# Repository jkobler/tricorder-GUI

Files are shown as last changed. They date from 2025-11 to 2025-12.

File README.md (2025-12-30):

# tricorder-GUI
**I'm building a fully (esque) functional TOS-era [Tricorder](http://www.racprops.com/issue5/classictricorder/index.php) using Arduino C++ and assorted compatibles.** 

## Task List
- [X] Blinky Lights™
- [X] Get TFT working
- [X] Make Menu System
- [X] Make Stardate Calculator
- [ ] Connect Working RTC
- [X] Button 1 and Button 2 do things like back and forward
- [X] Get I2C bus functioning
- [ ] Connect hood MCU to body MCU
- [X] Get Navigation Encoder Connected and Working
	- [X] ..Solder Encoder to Breakout Board
- [ ] Move components from breadboard to functional connects
- [ ] Solder switchs and Blink Lights™ to perf board then to hood MCU GPIO pins, or GPIO extender
- [ ] Solder TFT to hood MCU SPI pins
- [ ] Route power connections
- [ ] Get battery system working with low charge warning and charge status
- [ ] Print 3D parts.
- [ ] Standby mode
- [ ] Auto shutoff
- [ ] screen brightness
- [ ] audio
	- [ ] microphone and recording
	- [ ] speaker and audio playback
	- [ ] volume, gain, timbre(?)
- [ ] video
	- [ ] camera(s) and recording
	- [ ] video playback
- [ ] infrared camera and monitoring
- [ ] all the sensors
- [ ] Write the rest of this list
- [ ] Initiate scope creep.

## Current Schematics
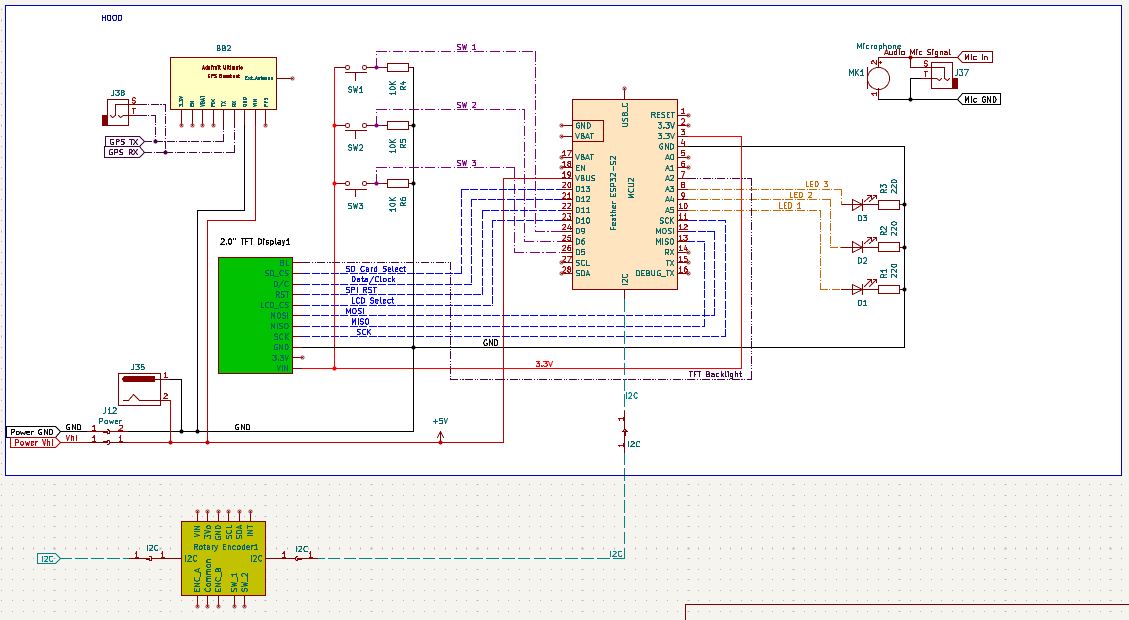
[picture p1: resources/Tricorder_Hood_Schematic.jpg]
Wiring Diagram


## LOGS

### 2025-11-16

It all started when I started 3D printing a [Tricorder](https://cults3d.com/en/3d-model/various/tos-tricorder-with-empty-compartment) model and then thought to myself, "Hey, I should put a little screen along with an MCU and then make it do tricorder stuff." It kind of went from there. 

So far, I have a working first go at a GUI, which I had to take liberties with as there were very few times we ever saw the little screen on the hero models. I tried to keep a look and feel that I thought might be privelent in the mid-23rd century, and not go full LCARS with it. Personally, I don't like LCARS but that's me. I went with something a bit more minimalistic and easy to read on the small 320x240 sceen. Long, indented losenges.

I have stubs for some of the features. I did get a basic image veiwer working as well as a text reader. I also have blinky lights™. You can't have a tricorder without the blinky lights™, now can you? The answer is 'no' as if that question needs an answer. ALWAYS BLINKY LIGHTS™!

As of right now I plan on sticking with ESP32 processors as they seem to have the speed and memory to handle everything without issue. I currently have an [Adafruit Metro ESP32-S2](https://www.adafruit.com/product/2488) as the processor now, which is running the screen and the blinky lights™. I plan on using a smaller [Adafruit ESP32-S2 Feather](https://www.adafruit.com/product/5000) for the [Adafruit 2.2" ILI9341 based TFT](https://www.adafruit.com/product/1480), the blinky lights™ of course, and the buttons. All of these should fit up in the hood along with the screen, and require only power and I2C connections routed from the body. There will also probably be a microphone in the hood but I would prefer it be connected to the body processor which will most likely be the Adafruit Metro ESP32-S2 I already have in play. 

#### Punchdown List

| Auxilliary Device | Pin On Aux | MCU | Pin On MCU | Wire Color |
| :--- | :--- | :--- | :--- | :--- |
| 2.2" TFT | FPC Conn | EYESPI | FPC Conn | |
| EYESPI | Vin | Metro ESP32-S2 | 3.3 | |
| EYESPI | Gnd | Metro ESP32-S2 | GND | |
| EYESPI | SCK | Metro ESP32-S2 | SCK | blue |
| EYESPI | MOSI | Metro ESP32-S2 | MOSI | orange |
| EYESPI | MISO | Metro ESP32-S2 | | |
| EYESPI | DC | Metro ESP32-S2 | D9 | yellow |
| EYESPI | RST | Metro ESP32-S2 | RST | brown |
| EYESPI | TCS | Metro ESP32-S2 | D10 | green |
| EYESPI | SDSC | Metro ESP32-S2 | D12 | gray |
| SWITCH1 | 1 | Metro ESP32-S2 | D7 | purple |
| SWITCH1 | 2 | Metro ESP32-S2 | GND | black |
| SWITCH2 | 1 | Metro ESP32-S2 | D8 | yellow |
| SWITCH2 | 2 | Metro ESP32-S2 | GND | black |
| SWITCH3 | 1 | Metro ESP32-S2 | D6 | orange |
| SWITCH3 | 2 | Metro ESP32-S2 | GND | black |
| SWITCH4 | 1 | Metro ESP32-S2 | D5 | blue |
| SWITCH5 | 2 | Metro ESP32-S2 | GND | black |
| BlinkyLight1 | Anode | Metro ESP32-S2 | D13 | red | 
| BlinkyLight1 | Cathode | Metro ESP32-S2 | GND | 10kΩ |  
| BlinkyLight2 | Anode | Metro ESP32-S2 | D14 | white | 
| BlinkyLight2 | Cathode | Metro ESP32-S2 | GND | 10kΩ |  
| BlinkyLight3 | Anode | Metro ESP32-S2 | D15 | brown | 
| BlinkyLight3 | Cathode | Metro ESP32-S2 | GND | 10kΩ |  
| | | | |  

##### Display Punchdown List

| Auxilliary Device | Pin On Aux | MCU | Pin On MCU | Wire Color |
| :--- | :--- | :--- | :--- | :--- |
| 2.2" TFT | GND | Metro ESP32-S2 | GND | black |
| 2.2" TFT | VIN | Metro ESP32-S2 | 3.3 | brown |
| 2.2" TFT | D/C | Metro ESP32-S2 | D9 | red |
| 2.2" TFT | RST | Metro ESP32-S2 | RST | orange |
| 2.2" TFT | SDCS | Metro ESP32-S2 | D12 | yellow |
| 2.2" TFT | CS | Metro ESP32-S2 | D10 | green |
| 2.2" TFT | MOSI | Metro ESP32-S2 | MOSI | blue |
| 2.2" TFT | MISO | Metro ESP32-S2 | MISO | purple |
| 2.2" TFT | SCK | Metro ESP32-S2 | SCK | gray |
| 2.2" TFT | BL | Metro ESP32-S2 | XXXXXXXXXX | white |

##### Switch Array Punchdown List

| Auxilliary Device | Pin On Aux | MCU | Pin On MCU | Wire Color |
| :--- | :--- | :--- | :--- | :--- |
| SWITCH1 | | Metro ESP32-S2 | D7 | purple |
| SWITCH2 | | Metro ESP32-S2 | D8 | green |
| GND | | Metro ESP32-S2 | GND | blue |

##### Blinky Lights™ Array Punchdown List

| Auxilliary Device | Pin On Aux | MCU | Pin On MCU | Wire Color |
| :--- | :--- | :--- | :--- | :--- |
| LED1 | | Metro ESP32-S2 | D13 | purple |
| LED2 | | Metro ESP32-S2 | D14 | green |
| LED3 | | Metro ESP32-S2 | D15 | blue |
| GND | | Metro ESP32-S2 | GND | black |

### 2025-12-17

Had to take break to print parts, order parts, and work on other projects, but I was able to hook up the blinky lights™ on a [Adafruit GPIO Extender](https://www.adafruit.com/product/4886) and the encoder with an [Adafruit Rotary Encoder Breakout](https://www.adafruit.com/product/4991) to the [Adafruit ESP32-S2 Feather](https://www.adafruit.com/product/5000). That works so much nicer. The lights can fade in and out which is classy af.

I almost forgot to mention I bought I new 3D-printer which is what brought me back into this full berries. My Creality Ender 3 S1 Plus has unfortunately ended up with a warped hot bed, I imagine because it is rather wide and long, but also perhaps because I didn't let it cool slower. Just theories, but I can't find a replacement hotbed for it, and since we have the laser cutter attachment which isn't so sensitive to tram and level issues, it will be for laser cutting from here on out. I replaced it with an Anycubic Kobra S1 combo kit with the ACE filament box which allows me to do multicolor. So far it has been wonderful. I mean, I was printing right out of the box which I couldn't do with the Creality.

While the Ender 3 was I struggle sometimes, I don't regret getting it. I learned a lot, and when it worked, it worked well. For the price point, it worked well. I will still be able to use it as mentioned, for laser cutting. I would still be using it if Creality hadn't abandon making replacement parts for it a year after I bought it, but such are things with bleeding edge technology I guess.

Nonetheless, I can now print my tricorder parts after making changes necessary for fitting the parts.

Ok, back to the Tricorder.

I also picked up a couple of [Adafruit 2.0" 320x240 TFT Displays](https://www.adafruit.com/product/4311) from Digikey which will provide better fitment. The goal is to get one working with the ESP32-S2 Feather along with everything else so the buttons and encoder can interact with the menu system. I am going to ditch the EYESPI board. It's great for debugging and prototyping but room is a factor and the ribbon cable doesn't fit so I will have to direct solder, maybe with a different connector between for easy replacement. Adafruit has more of the 2.0" TFTs back in stock so I'll probably order more from there. It's nice to have spares, not to mention like all projects this is merely the prototype. Actually, the next 5 will mostly be prototypes too if I'm being honest here.

I printed a handy test stand for my hood parts (STL is included in this repo) that will assist me in prototype and

I'm going to have to change to the buttons inputting to and the LEDs fed from the MCU directly. There just isn't going to be room in the hood for the GPIO Extender, not to mention it really didn't spare me any hassle as I still had to solder. I intend on using pulse width modulation to get the same fade in and out effect though.

For switches I found these awesome badboys on DigiKey, [Pushbutton Switch SPST-NO](https://www.digikey.com/en/products/detail/e-switch/800AWSP9M2QE/502069). Not tactile but they fit well. I re-make the train wheel buttons to fit over these. I'll probably pull them down to ground with 10KΩ resisters.

At this point I need to decide how I want to connect the blinky lights™, switches, and TFT to the MCU, and find connectors that will work for this setup.  

#### Punchdown List (expected)

| Auxilliary Device | Pin On Aux | MCU | Pin On MCU | Pull Up/Down  | Wire Color |
| :--- | :--- | :--- | :--- | :--- | :--- |
| 2.0" TFT | Vin | ESP32-S2 Feather | 3.3 | | |
| 2.0" TFT | 3Vo | | | | |
| 2.0" TFT | Gnd | ESP32-S2 Feather | GND | | |
| 2.0" TFT | SCK | ESP32-S2 Feather | SCK | | |
| 2.0" TFT | MISO | ESP32-S2 Feather | MI | | |
| 2.0" TFT | MOSI | ESP32-S2 Feather | MO | | |
| 2.0" TFT | CS | ESP32-S2 Feather | D13 (GPIO14) | | |
| 2.0" TFT | RST | ESP32-S2 Feather | D12 (GPIO14) | | |
| 2.0" TFT | D/C | ESP32-S2 Feather | D11 (GPIO14) | | |
| 2.0" TFT | SDSC | ESP32-S2 Feather | D10 (GPIO14) | | |
| 2.0" TFT | BL | ESP32-S2 Feather | | | |
| SWITCH1 | 1 | ESP32-S2 Feather | D9 (GPIO9) | 10kΩ to GND | |
| SWITCH1 | 2 | ESP32-S2 Feather | 3.3V | | |
| SWITCH2 | 1 | ESP32-S2 Feather | D6 (GPIO6) | 10kΩ to GND | |
| SWITCH2 | 2 | ESP32-S2 Feather | 3.3V | | |
| SWITCH3 | 1 | ESP32-S2 Feather | D5 (GPIO5) | 10kΩ to GND | |
| SWITCH3 | 2 | ESP32-S2 Feather | 3.3V | | |
| BlinkyLight1 | Cathode | ESP32-S2 Feather | A5 (GPIO8) | | | 
| BlinkyLight1 | Anode | ESP32-S2 Feather | 3.3V | 220Ω to 3.3V  | |  
| BlinkyLight2 | Cathode | ESP32-S2 Feather | A4 (GPIO14)  | | | 
| BlinkyLight2 | Anode | ESP32-S2 Feather | 3.3V | 220Ω to 3.3V  | |  
| BlinkyLight3 | Cathode | ESP32-S2 Feather | A3 (GPIO15)  | | | 
| BlinkyLight3 | Anode | ESP32-S2 Feather | 3.3V | 220Ω to 3.3V  | |  

##### I2C Bus

| Auxilliary Device | Address | MCU | Constant Name | 
| :--- | :--- | :--- | :--- |
| Encoder Breakout  | 0x36 | ESP32-S2 Feather | SEESAW_ADDR |

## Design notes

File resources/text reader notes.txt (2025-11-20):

For a number of years work has been proceeding in order to bring perfection to the crudely conceived idea of a machine that would not only supply inverse reactive current for use in unilateral phase detractors, but would also be capable of automatically synchronizing cardinal grammeters.  Such a machine is the Turbo-Encabulator. Basically, the only new principle involved is that instead of power being generated by the relative motion of conductors and fluxes, it is produced by the modial interaction of magneto-reluctance and capacitive directance.

text = For a number of years work has been proceeding in order to bring perfection to the crudely conceived idea of a machine that would not only supply inverse reactive current for use in unilateral phase detractors, but would also be capable of automatically synchronizing cardinal grammeters.

  int pageNumber = 0;
  int lastChar = 0;
  int maxCharsPerScreen = 0;
  int textLength = 288;
  byte linesPerScreen =11;
  //int avgCharWidth=0;
  byte charsPerLine = 38;
  bool stillReading = true;
  int i=0,lastSpaceInLine=0,lineCount=0, estLinesTotal = (textLength/(charsPerLine))+2;
  char lineBuffer[charsPerLine+1];
  char formattedText[estLinesTotal][charsPerLine+1];

LOOP over characters (ch) in text , ch < textLength; Bascially ch is 0 to 287
	
	LOOP over characters to fill a line. i < charsPerLine && ch < textLength;  i is 0 to 38
		
		if ch is a space, newline, or punctuation, record i (by the lineBuffer being built) as lastSpaceInLine

		add this character to lineBuffer in idx i
	                                                    0         1         2         3    3      
	                                                    0123456789012345678901234567890123456789
	                                                    For a number of years work has been proc
														abcdefghijklmnopqrstuvwxyzABCDEFGHIJKLMNO
														abcdefghijklmnopqrstuvwxyzABCDEFGHIJKL MNO
    scenarios                                                                     lastSpaceInLine                ch
      1. We've transversed the whole line (i = 38), we are still ch<textLength, 
         and there is a white space character before that but past 60% (23)       The last space encountered;    back to last white space.
      2. We've hit the end of the text (ch >= textLength)                         i-1;                           no change
      3. We've transversed the whole line (i = 38), we are still ch<textLength,   i-1;                           no change
         there is either no whitespace before 60%, but there is whitespace the 
         next character up.
      4. We've transversed the whole line (i = 38), we are still ch<textLength,   i-1;                           no change
         there is either no whitespace before 60%.
														
scenario 1
			ch = 38 (index)
			i=38 (index)
			lastSpaceInLine = 35 (index)
			charsPerLine = 38 (total)
			ch correction = 38-35+1 = 2

	END LOOP ch < charsPerLine && ch < textLength
	
	if the next character in the text (text(ch+1)) is a space, newline, or punctuation, record i (by the lineBuffer being built) as lastSpaceInLine and ch+1 < textLength then lastSpaceInLine = i
	
	copy 

For a number of years work has been proce           41
eding in order to bring perfection to the cru       45
dely conceived idea 
of a machine that would not only supply inv         43
erse reactive current for use in unilateral ph      46
ase detractors, 
but would also be capable of automatically          43
synchronizing cardinal grammeters.  Such a          44
machine is the 
Turbo-Encabulator. Basically, the only new          43
principle involved is that instead of power b       45
eing generated by the relative motion of conductors and fluxes, it is produced by the modial interaction of magneto-reluctance and capacitive directance.

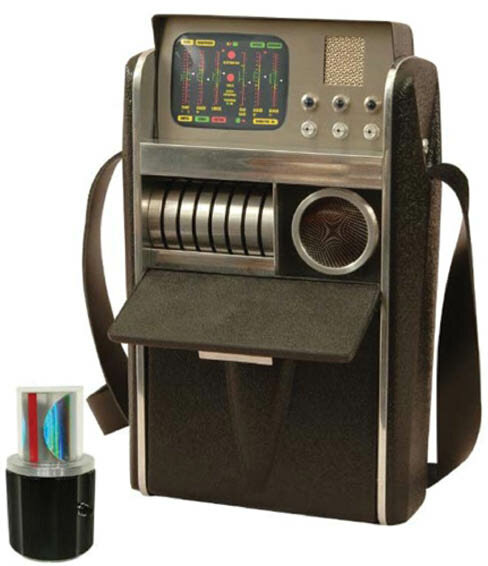
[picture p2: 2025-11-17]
resources/images/reference photos/hero/The-original-Tricorder-model-and-probe-used-on-the-Star-Trek-television-series-designed.png

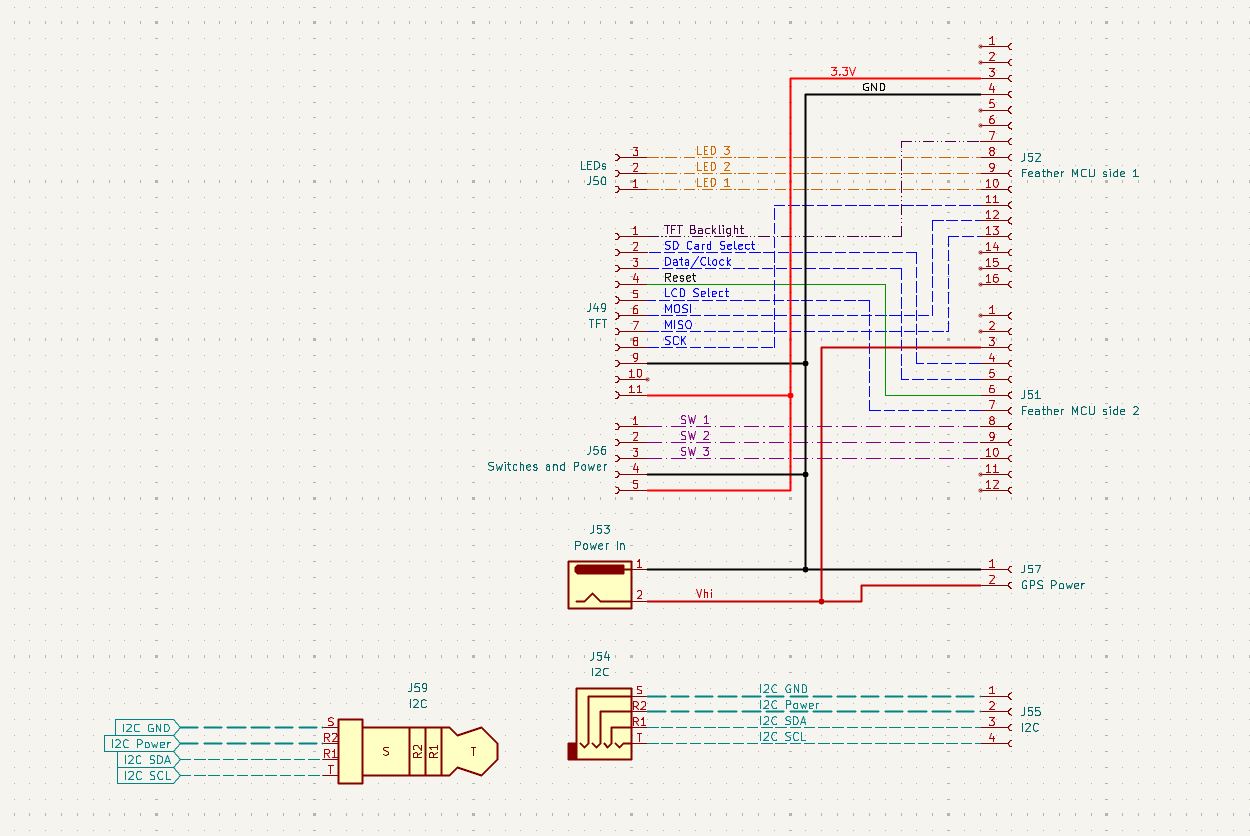
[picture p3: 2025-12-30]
resources/Tricorder_Hood_Wire_Harness_Schematic.jpg

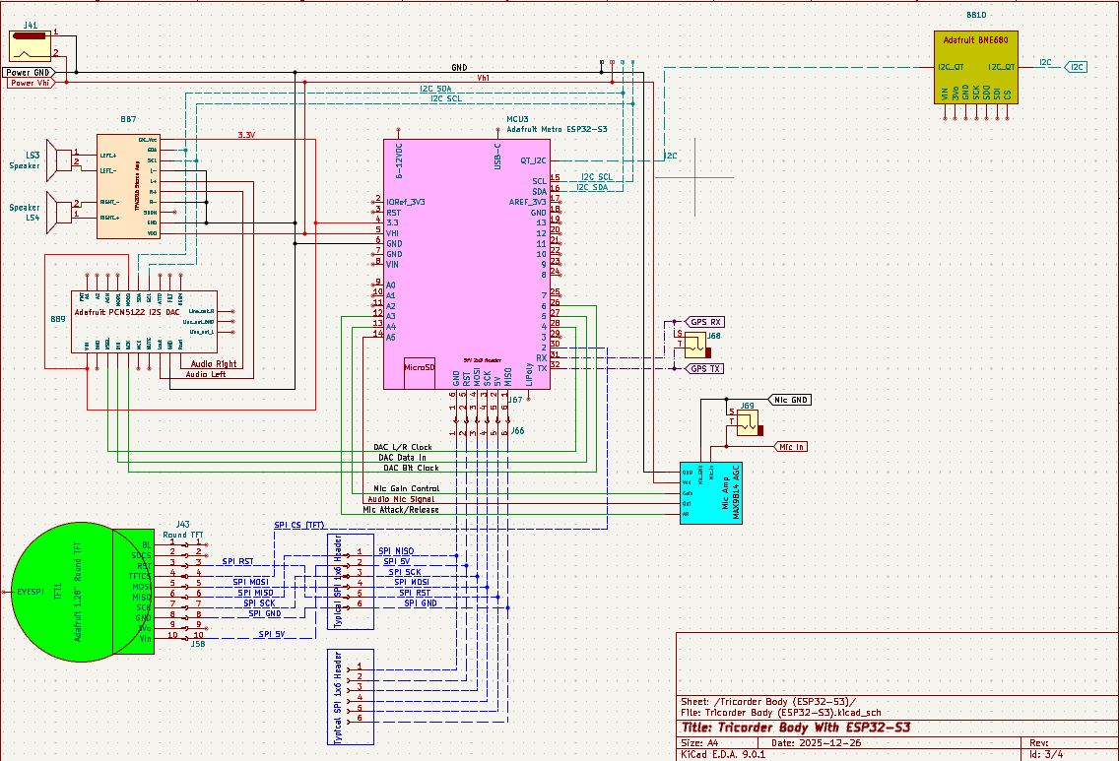
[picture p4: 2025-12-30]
resources/Tricorder_Body_Schematic.jpg

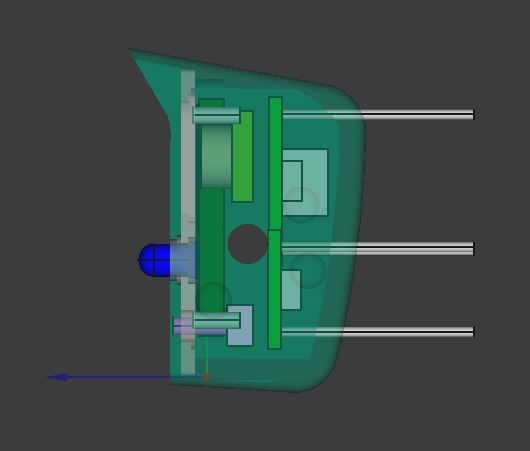
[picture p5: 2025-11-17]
resources/images/reference photos/layout/Tricorder hood-Right.JPG

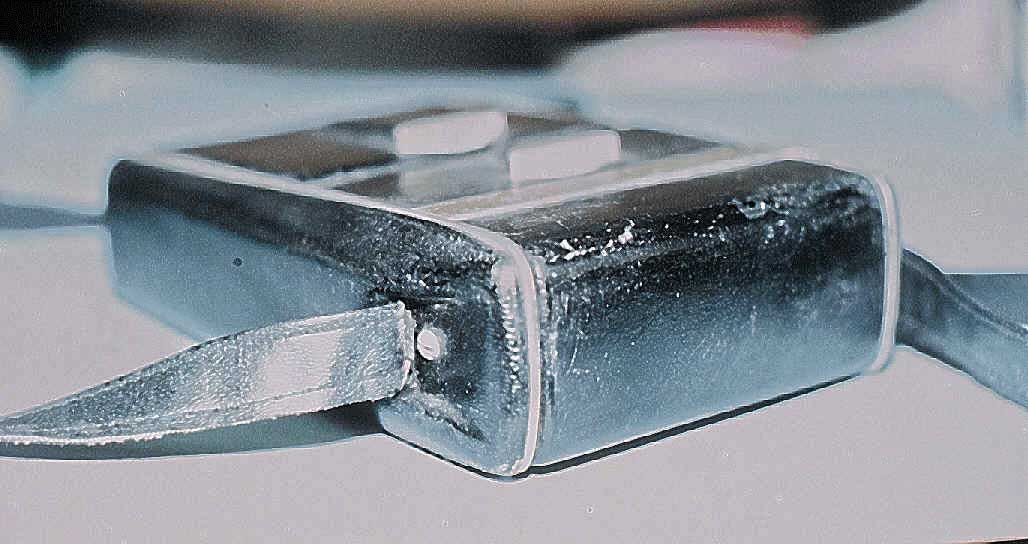
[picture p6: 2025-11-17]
resources/images/reference photos/hero/tricorder14.jpg

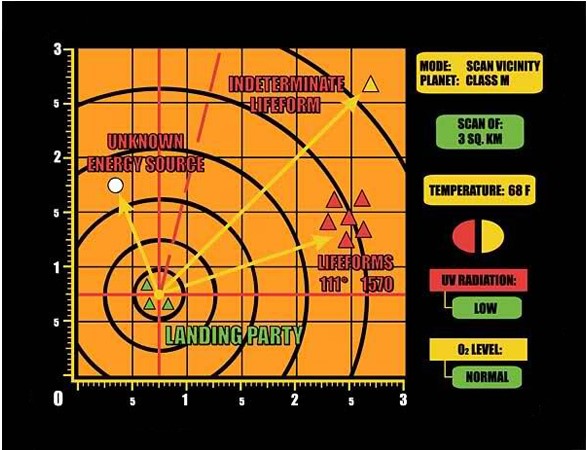
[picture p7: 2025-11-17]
resources/images/Tricorder Screen 1.jpg

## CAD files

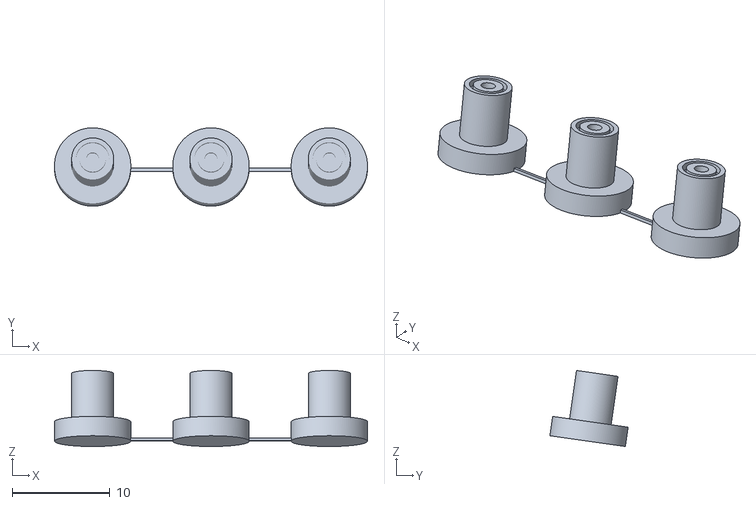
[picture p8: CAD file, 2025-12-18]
resources/3D Models/01. TOS Tricorder(Empty)-STL Files/TTA1-Hood buttons.stl
32.0 x 8.02 x 7.79

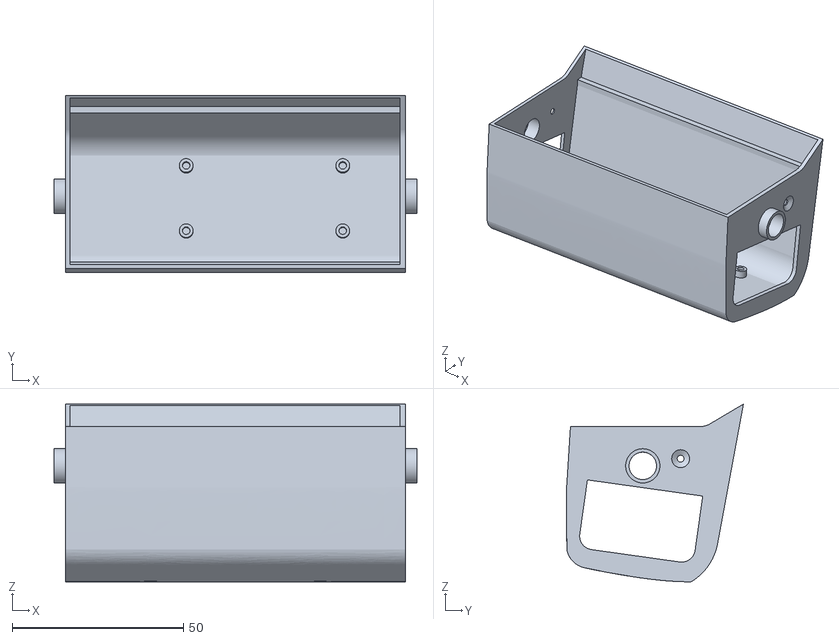
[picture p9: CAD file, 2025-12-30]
resources/3D Models/TRHV4-Hood test Shell.stl
106.0 x 51.7 x 51.9

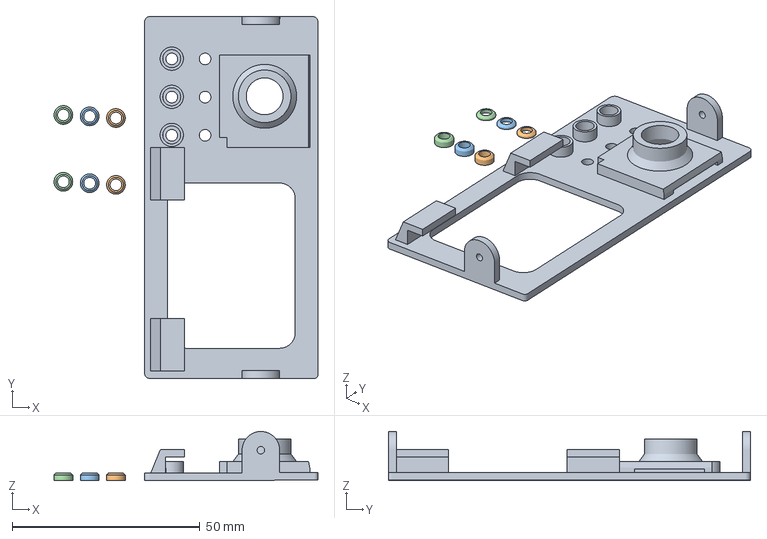
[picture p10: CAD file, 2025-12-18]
resources/images/TRHV4-Hood Front Panel.3mf
70.3 x 96.4 x 13.1 mm
TRHV4-Hood Front Panel.stl
TRHV4-Button Surround x 3

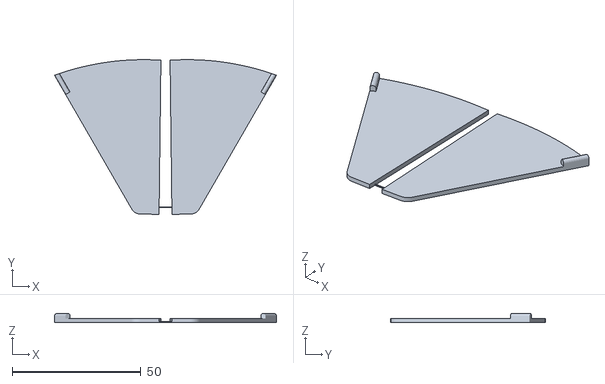
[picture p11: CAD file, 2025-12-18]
resources/3D Models/01. TOS Tricorder(Empty)-STL Files/TTA1-Door Catches.stl
86.1 x 60.0 x 3.50

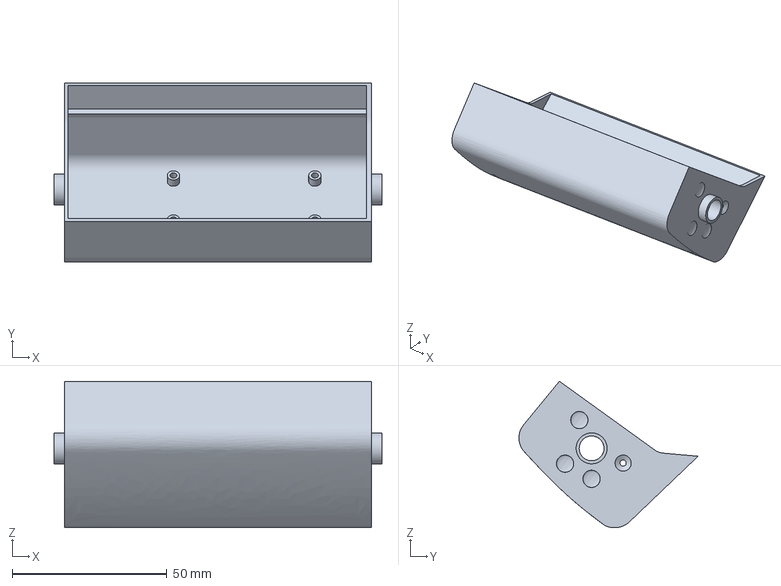
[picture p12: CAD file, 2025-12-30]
resources/3D Models/TRHV4-Hood Shell.3mf
106.0 x 57.9 x 47.3 mm

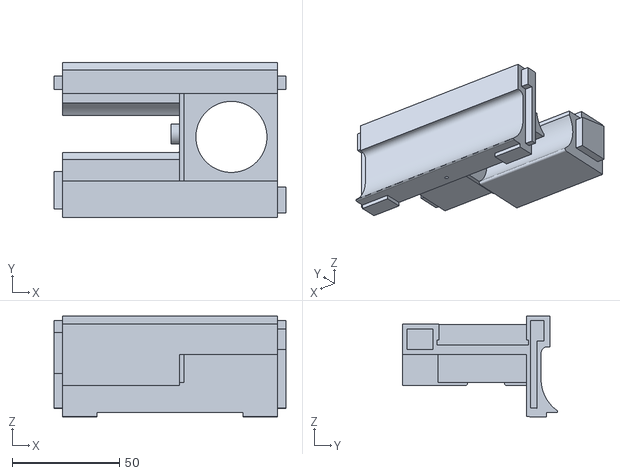
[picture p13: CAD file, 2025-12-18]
resources/3D Models/01. TOS Tricorder(Empty)-STL Files/TTA1-Internal Frame.stl
108.0 x 72.3 x 47.0

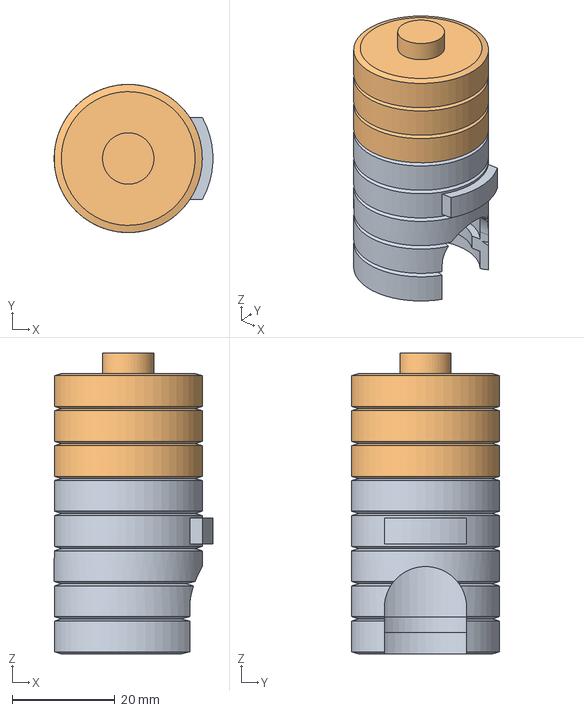
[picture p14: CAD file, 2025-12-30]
resources/3D Models/TTA1-Disk Encoder.FCStd
30.8 x 28.8 x 58.5 mm
Disk Encoder Casing
Disk Encoder Knob

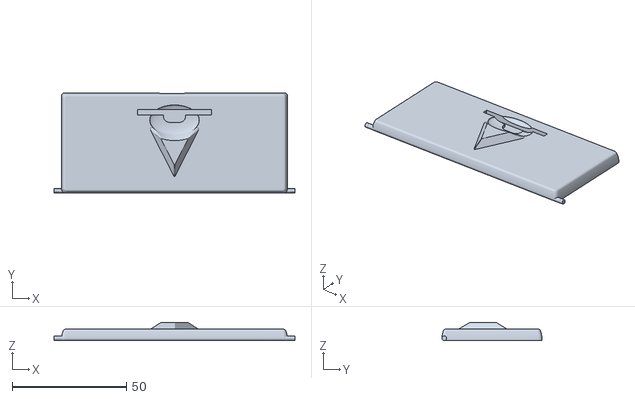
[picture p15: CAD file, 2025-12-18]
resources/3D Models/01. TOS Tricorder(Empty)-STL Files/TTA1-Upper Door (Handle B) (with magnet slot).stl
105.4 x 44.0 x 8.00

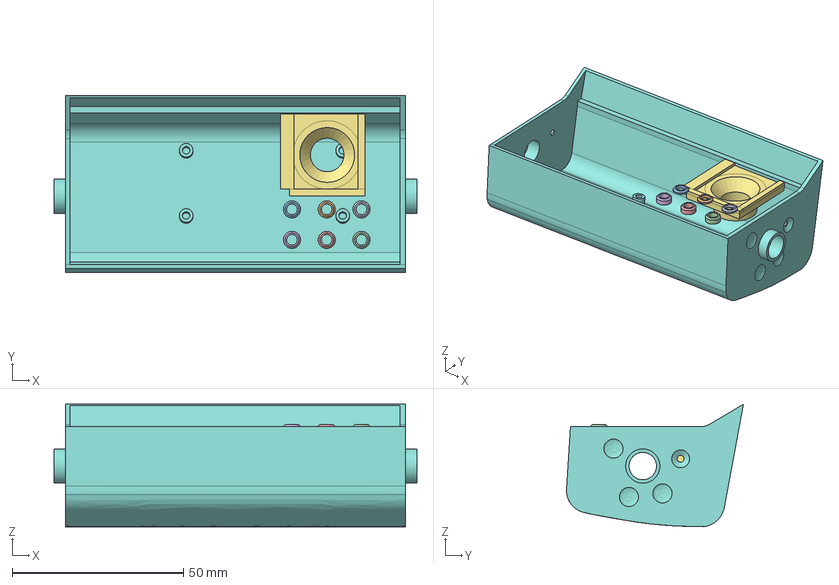
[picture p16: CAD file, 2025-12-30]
resources/3D Models/Tricorder screen fit V4.FCStd
106.0 x 51.7 x 35.8 mm
LED Surround 001
LED Surround 002
LED Surround 003
Button Surround 001
Button Surround 002
Button Surround 003
Hood MIc Bezel
Hood

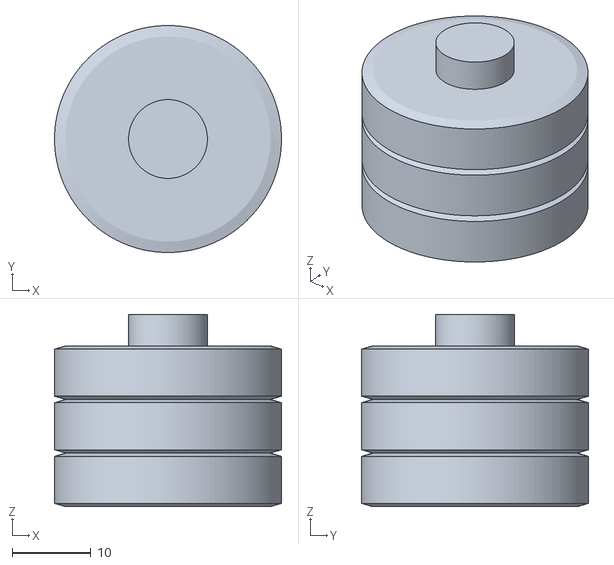
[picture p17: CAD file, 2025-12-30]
resources/3D Models/TTA1-Disk Encoder Knob.stl
28.8 x 28.8 x 24.4

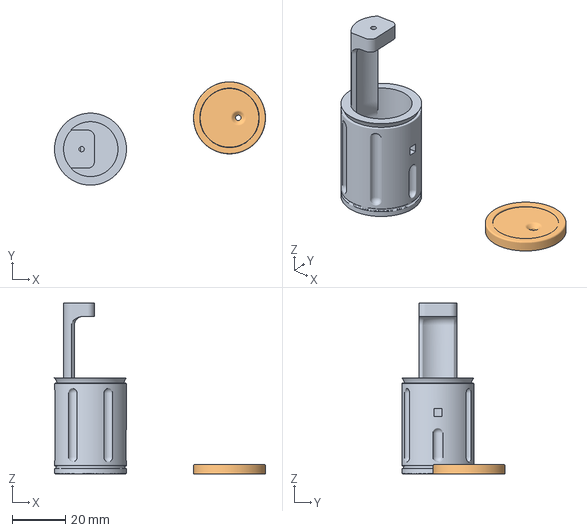
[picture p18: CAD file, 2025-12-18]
resources/3D Models/01. TOS Tricorder(Empty)-STL Files/TT-Science Scanner 1.3mf
79.1 x 38.7 x 64.0 mm
TT-Science Scanner 1.stl
TT-Science Scanner 3.stl

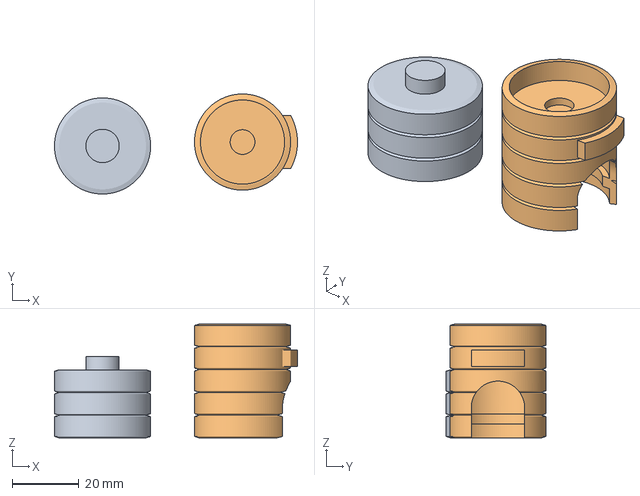
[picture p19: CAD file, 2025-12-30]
resources/3D Models/TTA1-Disk Encoder Casing.3mf
72.8 x 30.0 x 34.1 mm
TTA1-Disk Encoder Knob.stl
TTA1-Disk Encoder Casing.stl

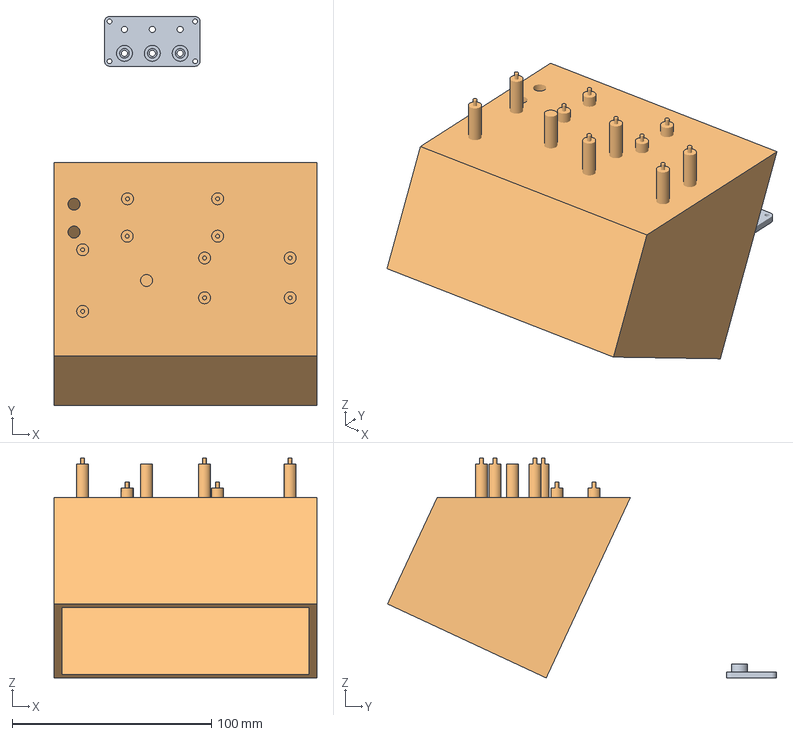
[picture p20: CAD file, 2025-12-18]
resources/3D Models/Tricorder Test Stands- hood.3mf
132.0 x 195.4 x 110.5 mm
Tricorder Test Stands-Hood buttons and LEDs.stl
Tricorder Test Stands-Hood Test Stand.stl

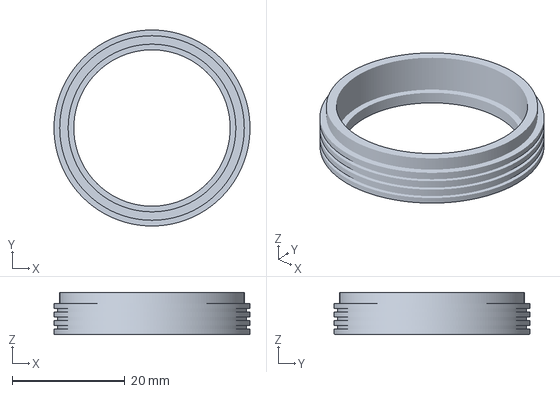
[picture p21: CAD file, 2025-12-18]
resources/3D Models/01. TOS Tricorder(Empty)-STL Files/TTA1-Lens Rim.3mf
34.7 x 34.7 x 7.50 mm

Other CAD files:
resources/3D Models/01. TOS Tricorder(Empty)-STL Files/TTA1-Upper Door (Handle A) (with magnet slot).stl
resources/3D Models/01. TOS Tricorder(Empty)-STL Files/TTA1-Upper Door (Handle B).stl
resources/3D Models/Tricorder Test Stands-Hood buttons and LEDs.stl
resources/3D Models/01. TOS Tricorder(Empty)-STL Files/TTA1-Lens frame panel.stl
resources/3D Models/01. TOS Tricorder(Empty)-STL Files/TT-Science Scanner 1.stl
resources/3D Models/01. TOS Tricorder(Empty)-STL Files/TT-Science Scanner 2.stl
resources/3D Models/01. TOS Tricorder(Empty)-STL Files/TT-Science Scanner 3.stl
resources/3D Models/01. TOS Tricorder(Empty)-STL Files/TTA1- Left Side Frame.stl
resources/3D Models/01. TOS Tricorder(Empty)-STL Files/TTA1- Upper Door (Handle A).stl
resources/3D Models/01. TOS Tricorder(Empty)-STL Files/TTA1-Back (no screw hole).stl
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

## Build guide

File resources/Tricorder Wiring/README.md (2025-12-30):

# KiCAD 7 Feather Wing Template

This repo is a simple KiCAD template for Adafruit Feather Wings Specification.
Use it to quickly get started with the standard layout for Feather Wings to build your own sensor, driver, peripheral, etc. Wings.

board

This template is designed for use with [KiCAD 7](https://www.kicad.org/).

## How to use this template

Firstly either `git clone` or download the files in this repo.

Next, you will need to either add these files to your `KICAD_USER_TEMPLATE_DIR` path or change the path to point at this repo.

Typically `KICAD_USER_TEMPLATE_DIR` points at `/Users/your_username/Documents/KiCad/7.0/template/` on MacOS.
Once the path is correctly populated, navigate to `File -> New from Template` and choose `User Templates`.

You should now see a `Feather Wing Template`, select this and begin working on your new project.
Saving the project will prompt you to create a new project.

## Notes

This pinout is specific to the [Adafruit Feather Wing Specification](https://learn.adafruit.com/adafruit-feather/feather-specification) and thus may vary depending on the Feather Board you choose to target. For example, while the mechanical fit is correct, the pin names do not align with the [Feather Huzzah ESP8266](https://learn.adafruit.com/adafruit-feather-huzzah-esp8266/pinouts).

## Reference

- [Adafruit Feather Specification](https://learn.adafruit.com/adafruit-feather/feather-specification)

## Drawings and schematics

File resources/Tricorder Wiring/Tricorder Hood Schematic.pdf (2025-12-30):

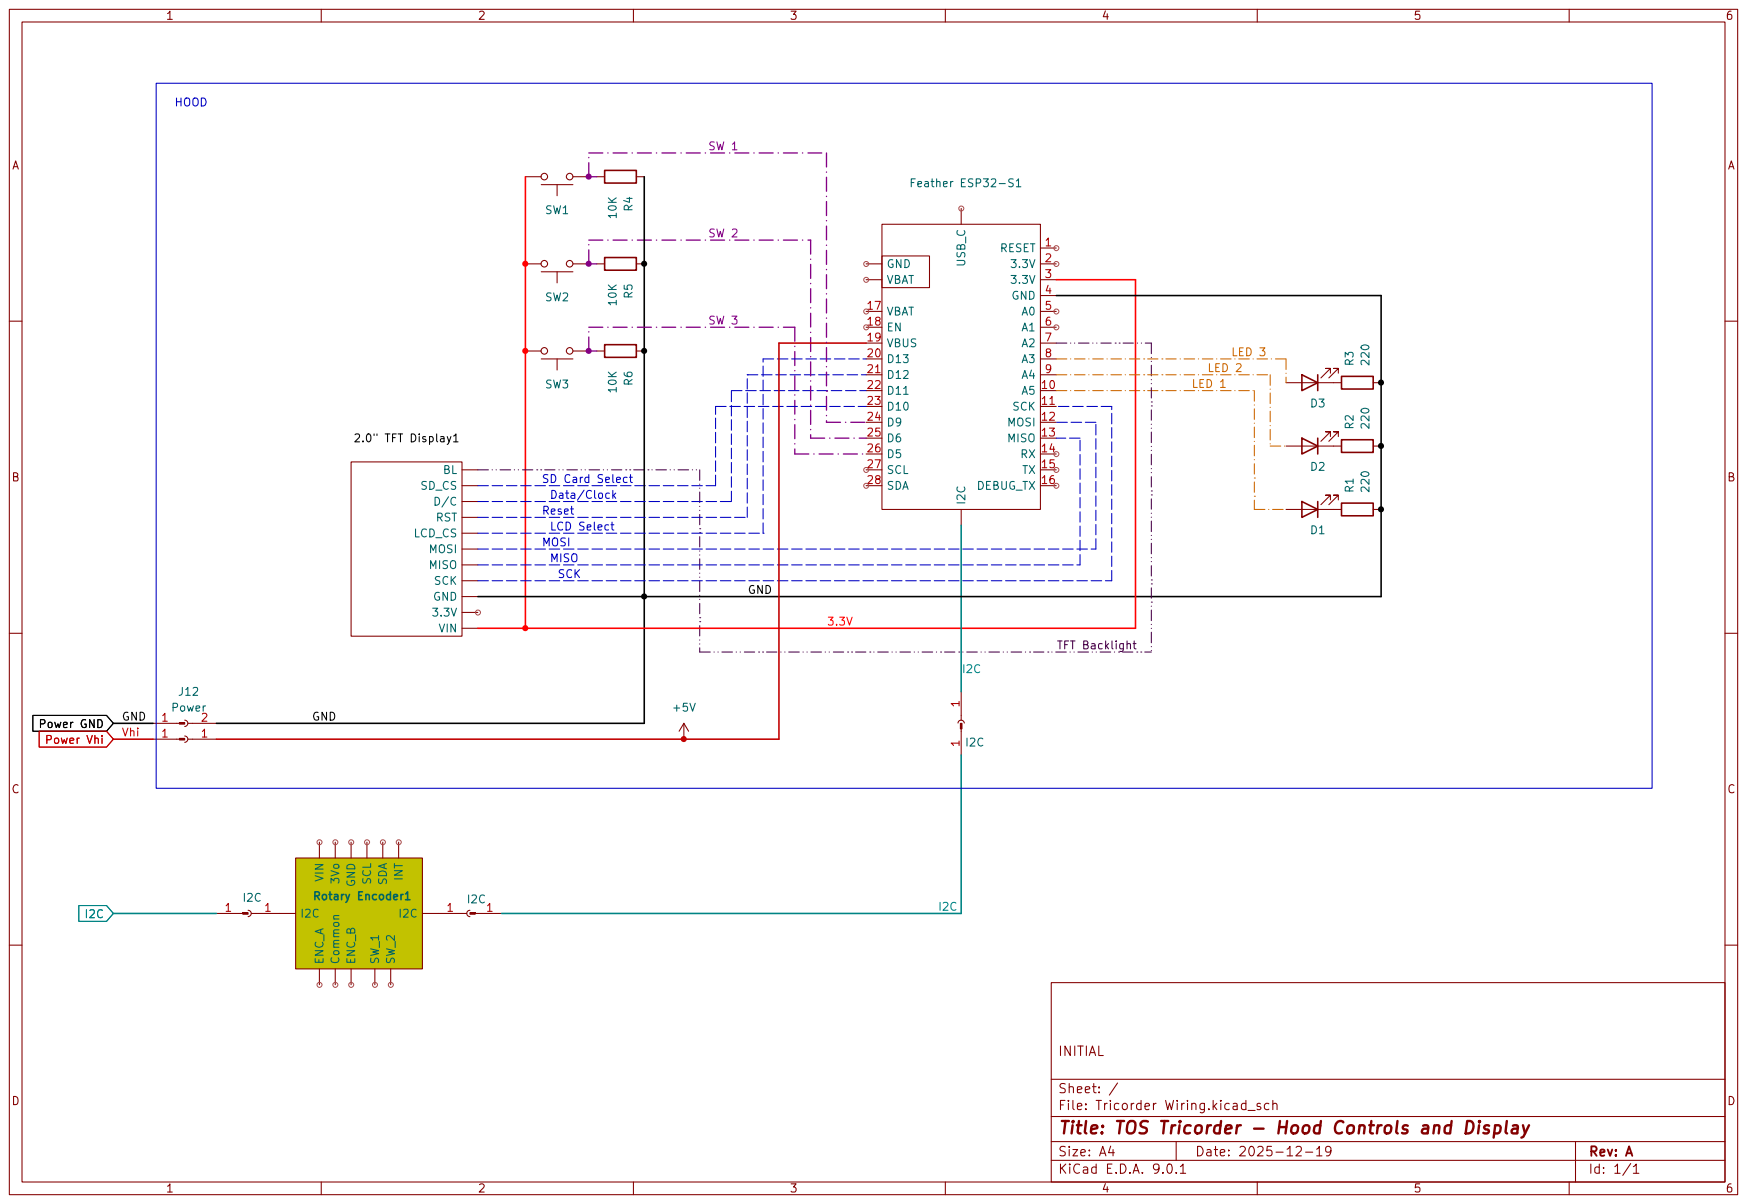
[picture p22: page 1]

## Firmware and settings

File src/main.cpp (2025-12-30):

#define DEBUG
//#define HAS_RTC
//#define USE_SD_CARD
//#define METRO_ESP32_S2
#define FEATHER_ESP32_S2
#define USE_BITMAP_ARRAY
//#define USE_PROGMEM_FOR_BITMAP_ARRAY
#define USE_I2C
//#define USE_ILI9341
#define USE_ST7789

#include <cstring>
#include <string.h>
#include "SPI.h"
#include "Adafruit_GFX.h"

#ifdef USE_ILI9341
  #include "Adafruit_ILI9341.h"
#endif

#ifdef USE_I2C
  #include "Adafruit_seesaw.h"
#endif

#ifdef USE_ST7789
  #include "Adafruit_ST7789.h"
#endif

#ifdef USE_SD_CARD
  #include "SdFat.h"
  #include "SdCard/SdCardInfo.h"
#endif

#include "Adafruit_ImageReader.h"
#include "fonts/FreeSans9pt7b.h"
#include "fonts/FreeSansBold9pt7b.h"
#include "fonts/FreeSans12pt7b.h"
#include "fonts/FreeSansBold12pt7b.h"
#include "fonts/FreeMono9pt7b.h"
#include "Fonts/FreeSerif9pt7b.h"
#include "Fonts/FreeSerifItalic9pt7b.h"
#include "pgmspace.h"
#include "chartingSystem.h"

#ifdef USE_BITMAP_ARRAY
  #include "bitmap_arrays_SFlogo.h"
#endif

#ifdef HAS_RTC
  #include "RTC.h"
#endif

// Color definitions
#define BLACK 0x0000
#define BLUE 0x001F
#define RED 0xF800
#define GREEN 0x07E0
#define DARKGREEN 0x03E0
#define CYAN 0x07FF
#define MAGENTA 0xF81F
#define YELLOW 0xFFE0
#define WHITE 0xFFFF

#define GRAY 0xBBBB
#define LIGHTGREY 0xC618
#define DARKCYAN 0x03EF
#define GREENYELLOW 0xAFE5
#define PINK 0xFC18

#ifdef USE_I2C
  #define SEESAW_ADDR 0x36
#endif
/*
COLORS:
  16 bit values 
  0-4 = Blue
  5-10 = Green
  11-15 = Red

TOS pallet.

#fdcd06	(253,205,6)    11111 110011 00001
#b9c92f	(185,201,47)   10111 110010 00110
#bf0f0f	(191,15,15)    11000 000100 00010
#165fc5	(22,95,197)    00011 011000 11000
#11709f	(17,112,159)   00011 011100 10100

From scanner pic
#756643 limeGreen
#ff9b25 orange
#eece2d yellow
#eb4035 red
font                 xAdvance  yAdvance

FreeMono9pt7b        11        18
FreeMonoBold9pt7b    11        18
FreeMono12pt7b       14        24
FreeMonoBold12pt7b   14        24
FreeMono18pt7b       21        35
FreeMonoBold18pt7b   21        35
FreeMono24pt7b       28        47
FreeMonoBold24pt7b   28        47

FreeSans9pt7b        5..18     22
FreeSansBold9pt7b    5..18     22
FreeSans12pt7b       6..24     29
FreeSans18pt7b       9..36     42
FreeSans24pt7b       12..48    56

FreeSerif9pt7b       5..17     22

*/

#define TOS_YELLOW 0b1110100011000110
#define TOS_LIMEGREEN 0b1011111001000110
#define TOS_RED 0b1110101000000111
#define TOS_ORANGE 0b1111110011100101
#define TOS_BLUE 0x1B18
#define TOS_SLATEBLUE 0x1B94

#define TFT_DC 12
#define TFT_CS 10
#define TFT_BL A2

#define SD_CS 13
#define TFT_RST 11

void loop();
void drawMenuItem(int, int, int, int, byte);
void drawMenu();
void handleSwitch1();
void handleSwitch2();
void handleSwitch3();
void constantLights(int8_t,byte);
void blinkyLights(int8_t, uint16_t);
void drawLogoBitmap();
void drawLogoBitmap(uint32_t delayTime);
void openAudioScreen();
void openVideoScreen();
void printCenterJustifiedText(const char*, u_int16_t, bool, uint16_t, uint16_t);
void printPaginatedText(const char*,uint16_t,uint16_t);
void openReaderScreen();
void fadeInLights(int8_t, uint8_t, uint16_t);
void fadeOutLights(int8_t, uint8_t, uint16_t);
void openBarChartTest();

#ifdef HAS_RTC
  void drawHeader(RTCTime);
  float StardateConverter(RTCTime, int);
#else
   void drawHeader();
#endif

#ifdef USE_SD_CARD
  SdFat                SD;         // SD card filesystem
  Adafruit_ImageReader reader(SD); // Image-reader object, pass in SD filesys
#endif

#ifdef USE_ILI9341
 Adafruit_ILI9341 tft = Adafruit_ILI9341(TFT_CS, TFT_DC);
#endif

#ifdef USE_ST7789
  Adafruit_ST7789 tft = Adafruit_ST7789(TFT_CS, TFT_DC, TFT_RST);
#endif

#ifdef USE_I2C
  Adafruit_seesaw ss;
#endif

typedef uint16_t Color;
typedef void (*FunctionCall)();


struct MenuItem {
  char label[25];
  byte toMenuGroup;
  FunctionCall toFunctionCall;		
};


struct MenuGroup {
  byte id;
  char label[20];
  struct MenuItem menuItems[20];
  byte itemCount;
  Color activeColor;
  Color inactiveColor;
  Color activeTextColor;
  Color inactiveTextColor;
};


const struct MenuGroup menuGroups[6] = {
  { 0,"Home",{{"Media",1},{"Information",2},{"Sensors",3},{"Turbo encabulator",4},{"Settings",5}},5,TOS_ORANGE,TOS_LIMEGREEN,BLACK,BLACK },
  { 1,"Media",{{"Back",0},{"Audio",0,openAudioScreen},{"Images",0,drawLogoBitmap},{"Video",0,openVideoScreen},{"Reader",0,openReaderScreen}},5,TOS_LIMEGREEN,GREEN,BLACK,BLACK },
  { 2,"Information",{{"Back",0},{"Lookup",0},{"Download",0},{"Upload",0}},4,CYAN,TOS_SLATEBLUE,BLACK,WHITE },
  { 3,"Sensors",{{"Back",0},{"Perimeter",0},{"Environmental",0,openBarChartTest}},3,TOS_ORANGE,RED,BLACK,WHITE },
  { 4,"Turbo encabulator",{{"Back",0},{"Unilateral Detractors",0},{"Synchronize Grammeter",0},{"HF Rem Peak Setting",0},{"Write-only Memory",0}},5,MAGENTA,TOS_SLATEBLUE,WHITE,WHITE },
  { 5,"Settings",{{"Back",0},{"Menu Item 42",0,drawLogoBitmap},{"Menu Item 43",0}},3,TOS_ORANGE,TOS_LIMEGREEN,BLACK,BLACK }
};

volatile int8_t activeMenuGroup=0;
volatile int8_t activeMenuItem=0;
volatile bool needsRefresh=1;
volatile bool onFunctionScreen=0;
volatile int loopCount = 0;

byte menuGroupCount = 5; //because sizeof is problematic

int screenWidth;
int screenHeight;
uint8_t screenRotation = 3;

byte switch1 = 9; 
byte switch2 = 6; 
byte switch3 = 5; 


//byte encoder_ = 6; //orange
//byte switch4 = 5; //blue
byte leds[3] = {A5,A4,A3};


volatile bool switch1State = 0;
volatile bool switch2State = 0;
volatile bool switch3State = 0;
volatile int lastMinutes = 0;
uint8_t maxBright = 128;
volatile uint8_t screenBright = 255;
uint8_t speed=2;
uint8_t totalLights= 3;
volatile int32_t prevEncPosition = 0;
volatile int8_t whichLight = 0;

void setup() {

    ImageReturnCode stat; // Status from image-reading functions
    Serial.begin(115200);

    pinMode(switch1,INPUT);
    pinMode(switch2,INPUT);
    pinMode(switch3,INPUT);

    pinMode(TFT_BL,OUTPUT);

    pinMode(leds[0],OUTPUT);
    pinMode(leds[1],OUTPUT);
    pinMode(leds[2],OUTPUT);


#ifdef HAS_RTC
    RTC.begin();
    //RTCTime startTime(dayInt, getMonthFromInt(monthInt), 2366, hourInt, minuteInt, 00, getDayOfWeekFromString(dayOfWeekStr), isDSTActive(isDSTActiveStr));
    RTCTime startTime(7, Month::JULY, 2266, 8, 0, 0, DayOfWeek::THURSDAY, SaveLight::SAVING_TIME_ACTIVE);
  
    RTC.setTime(startTime);
#endif

#ifdef USE_ILI9341
    tft.begin();
#endif

#ifdef USE_ST7789
    tft.init(240, 320);
#endif

    tft.setRotation(screenRotation);
    tft.setFont(&FreeSansBold12pt7b);
    

#ifdef DEBUG
    while(!Serial);
    Serial.println("TC25 Operating System\nVer 20251108a\nDEBUG MODE");
#endif
    analogWrite(TFT_BL, screenBright);
    delay(1000);
    screenWidth = tft.width();
    screenHeight = tft.height();

    tft.fillScreen(BLACK);
    tft.setTextColor(YELLOW);
    tft.setCursor(5, 17);
    tft.println("TC25 Operating System");
    tft.println("    Ver 20251219a");
    tft.setTextColor(BLUE);
    tft.println("  Turbo encabulator ");
    tft.println("      Edition");
    delay(2000);

#ifdef USE_SD_CARD
    if(!SD.begin(SD_CS)) { 
        Serial.println(F("SD begin() failed"));
        tft.fillScreen(BLACK);
        tft.setFont(&FreeSansBold9pt7b);
        tft.setCursor(1, 14);
        tft.setTextColor(RED,BLACK);    
        tft.println("SD begin() failed");
        printSdErrorText(&Serial,SD.sdErrorCode());
        printSdErrorText(&tft,SD.sdErrorCode());
        delay(1000);

        for(;;); // Fatal error, do not continue
    }
    Serial.println("SDCard initialization done.");
    tft.println("SDCard initialization done.");
#endif

#ifdef USE_I2C 
    Serial.println("Looking for seesaw!");
    if (! ss.begin(SEESAW_ADDR)) {
        Serial.println("Couldn't find seesaw on default address");
        while(1) delay(10);
    }
    Serial.println("seesaw started");

#endif


    delay(1000);
    tft.fillScreen(BLACK);
    delay(10);

    for(byte i; i < totalLights; i++) {
        fadeInLights(i, maxBright, speed);
        fadeOutLights(i, maxBright, speed);
    }

    for(int i = 0; i<11;i++) {
        blinkyLights(i%3, 255);
    }
    // /pics/Tricorder Screen 1.bmp
    // /pics/starfleet_TOS-2_black_bg.bmp

#ifdef USE_SD_CARD
    stat = reader.drawBMP("/pics/SF_TOS-1.bmp", tft, 0, 0);

    reader.printStatus(stat);   // How'd we do?
    #ifdef DEBUG
    switch (stat) {
        case IMAGE_ERR_FILE_NOT_FOUND:
            Serial.println("SF_TOS-1.bmp:Could not open the requested file");
            break;
        case IMAGE_ERR_FORMAT :
            Serial.println("SF_TOS-1.bmp:Not a supported image format");
            break;
        case IMAGE_ERR_MALLOC :
            Serial.println("SF_TOS-1.bmp:Could not allocate memory for operation");
            break;
        default:
            Serial.println("SF_TOS-1.bmp:Image loaded successfully");
    } 
    #endif   

#elifdef USE_BITMAP_ARRAY
    drawLogoBitmap();
#endif



#ifdef USE_BITMAP_ARRAY
   drawLogoBitmap();
#endif

#ifdef DEBUG
    Serial.println("Starting firmware");
    Serial.print("screenWidth:");
    Serial.println(screenWidth);
    Serial.print("screenHeight:");
    Serial.println(screenHeight);
#endif

    delay(2000);
    // attachInterrupt(switch3, handleSwitch3, FALLING);
    // attachInterrupt(switch4, handleSwitch4, FALLING);
    attachInterrupt(switch1, handleSwitch1, RISING);
    attachInterrupt(switch2, handleSwitch2, RISING);
    attachInterrupt(switch3, handleSwitch3, RISING);


}

void loop() {
#ifdef HAS_RTC  
    RTCTime currentTime;
    RTC.getTime(currentTime);
    int minutes = currentTime.getMinutes() + (currentTime.getHour()*60);
    if (lastMinutes != minutes) {
        needsRefresh = HIGH;
        lastMinutes = minutes;
    }
#endif
    byte prevWhichLight = whichLight;
    int32_t newEncPosition = ss.getEncoderPosition();
    
   
    if (newEncPosition != prevEncPosition) {
#ifdef DEBUG  
        Serial.print("loop(): prevEncPosition: ");
        Serial.print(prevEncPosition);
        Serial.print("; newEncPosition: ");
        Serial.print(newEncPosition);
        Serial.print("; activeMenuItem: ");
        Serial.println(activeMenuItem);
    //  delay(100);
#endif
        if (newEncPosition > prevEncPosition) {    
            //whichLight--;
            activeMenuItem--;
            //if (whichLight < 0) whichLight = totalLights-1; //it rolls over to 255
            if (activeMenuItem < 0) 
                activeMenuItem = menuGroups[activeMenuGroup].itemCount - 1;
        }
        else if (newEncPosition < prevEncPosition) {
            //whichLight++;
            activeMenuItem++;
            //if (whichLight >= totalLights) whichLight = 0;
            if (activeMenuItem >= menuGroups[activeMenuGroup].itemCount)  
                activeMenuItem = 0;
        }
        needsRefresh=true;
        prevEncPosition = newEncPosition; 

        //fadeOutLights(prevWhichLight, maxBright, speed);
        //fadeInLights(whichLight, maxBright, speed);
        //prevWhichLight = whichLight;

#ifdef DEBUG
        Serial.print("loop(): ");
        //Serial.print("; whichlight=");
        //Serial.print(whichLight);
        Serial.print("; activeMenuItem:");
        Serial.println(activeMenuItem);
#endif
        delay(200);
    

    } //if (rotaryClkVal != rotaryClkLastVal && rotaryClkVal == 0)

    if (switch2State == true) {
        blinkyLights(1,300);
#ifdef DEBUG
        Serial.println("Switch 2");
        Serial.print("loop(): ");
        Serial.println(menuGroups[activeMenuGroup].menuItems[activeMenuItem].label);
#endif

        if (onFunctionScreen==true) {
            onFunctionScreen = false;
            needsRefresh=true;
#ifdef DEBUG
            Serial.print(" is selected. Leaving screen for MenuGroup ");
            Serial.println(menuGroups[activeMenuGroup].menuItems[activeMenuItem].toMenuGroup);
#endif
        }
        else if (menuGroups[activeMenuGroup].menuItems[activeMenuItem].toFunctionCall == nullptr ) {
            activeMenuGroup = menuGroups[activeMenuGroup].menuItems[activeMenuItem].toMenuGroup;
            activeMenuItem = 0;
            needsRefresh=true;
#ifdef DEBUG
            Serial.print(" is selected. This calls MenuGroup ");
            Serial.println(menuGroups[activeMenuGroup].menuItems[activeMenuItem].toMenuGroup);
#endif
        }
        else {
            menuGroups[activeMenuGroup].menuItems[activeMenuItem].toFunctionCall();
            onFunctionScreen=true;
            activeMenuItem = 0;
            needsRefresh=false;
#ifdef DEBUG
            Serial.print(" is selected. This calls a screen ");
#endif
        }

    }

    if (switch1State == true) {
        blinkyLights(0,300);
        needsRefresh=true;  
        if (activeMenuGroup > 0 && onFunctionScreen==false) 
            activeMenuGroup--;
        activeMenuItem = 0; //depends on first group being back button
        onFunctionScreen=false;

#ifdef DEBUG 
        Serial.println("Switch 1");
        Serial.print("loop(): ");
        Serial.println("going back");
#endif
    }

    if (switch3State == true) {
        blinkyLights(2,300);
        Serial.println("Switch 3");
    }


    if (needsRefresh == true) {
#ifdef HAS_RTC
        drawHeader(currentTime);
#else
        drawHeader();
#endif
        drawMenu();
        needsRefresh = false;

#ifdef DEBUG      
        Serial.print("loop(): ");
        Serial.println(menuGroups[activeMenuGroup].menuItems[activeMenuItem].label);
#endif    

        //delay(500);
    }
    switch1State = false;
    switch2State = false;
    switch3State = false;


}


void handleSwitch1() {
    switch1State = true;
}

void handleSwitch2() {
    switch2State = true;
}

void handleSwitch3() {
    switch3State = true;
}

#ifdef HAS_RTC
void drawHeader(RTCTime currentTime) {
    int mx = 5;
    int my = 5;
    // byte wip = screenWidth-20;
    // byte hip = screenHeight/10;
    int wip = screenWidth-20;
    int hip = screenHeight/10;
    float starDate = StardateConverter(currentTime,0);
#ifdef DEBUG
    Serial.print("starDate:");
    Serial.println(starDate);

#endif
    tft.fillScreen(BLACK);
    //yield();
    tft.setFont(&FreeSansBold9pt7b);
    tft.fillRoundRect(mx, my, wip, hip, hip/2, menuGroups[activeMenuGroup].inactiveColor);
    yield();
    tft.setCursor(mx+10,my+(hip*.1)+14);
    tft.setTextColor(menuGroups[activeMenuGroup].inactiveTextColor,menuGroups[activeMenuGroup].inactiveColor);
    //tft.setTextSize(2);
    
    tft.print(menuGroups[activeMenuGroup].label);
    tft.print("  -  ");
    tft.println(starDate);
    yield();
}
#else
void drawHeader() {
    int mx = 5;
    int my = 5;
    // byte wip = screenWidth-20;
    // byte hip = screenHeight/10;
    int wip = screenWidth-20;
    int hip = screenHeight/10;

    tft.fillScreen(BLACK);
    //yield();
    tft.setFont(&FreeSansBold9pt7b);
    tft.fillRoundRect(mx, my, wip, hip, hip/2, menuGroups[activeMenuGroup].inactiveColor);
    yield();
    tft.setCursor(mx+10,my+(hip*.1)+14);
    tft.setTextColor(menuGroups[activeMenuGroup].inactiveTextColor,menuGroups[activeMenuGroup].inactiveColor);
    //tft.setTextSize(2);
    
    tft.print(menuGroups[activeMenuGroup].label);

    yield();
}
#endif

void drawMenu() {
    int wip = screenWidth-20;
    int hip = screenHeight/10;
    int mx = 15;
    int my = hip+9;

#ifdef DEBUG
        //char buffer[100];
        //sprintf(buffer,"activeMenuGroup: %d; menuItem: %d; mx: %d; my: %d; wip: %d; hip: %d",activeMenuGroup,i,mx,my,wip,hip );
        //Serial.println(buffer);
        Serial.print("drawMenu(): screenWidth:");
        Serial.println(screenWidth);
        Serial.print("drawMenu(): screenHeight:");
        Serial.println(screenHeight);
        Serial.print("drawMenu(): activeMenuGroup:");
        Serial.print(activeMenuGroup);
        Serial.print("; wip:");
        Serial.print(wip);
        Serial.print("; hip:");
        Serial.println(hip);
#endif
    mx += 10;
    wip -= 10;
    for ( int i = 0; i<menuGroups[activeMenuGroup].itemCount; i++ ) {

#ifdef DEBUG
        //char buffer[100];
        //sprintf(buffer,"activeMenuGroup: %d; menuItem: %d; mx: %d; my: %d; wip: %d; hip: %d",activeMenuGroup,i,mx,my,wip,hip );
        //Serial.println(buffer);
        // Serial.print("screenWidth:");
        // Serial.println(screenWidth);
        // Serial.print("screenHeight:");
        // Serial.println(screenHeight);

        Serial.print("drawMenu(): menuItem:");
        Serial.print(i);
        Serial.print("; mx:");
        Serial.print(mx);
        Serial.print("; my:");
        Serial.println(my);
#endif

        drawMenuItem(mx, my, wip, hip, i);
        //yield();
        my = my + (hip+4);

    }



}


void drawMenuItem(int x, int y, int wip, int hip, byte menuItemId) {
  
    uint16_t bgColor=menuGroups[activeMenuGroup].inactiveColor;
    uint16_t fgColor=menuGroups[activeMenuGroup].inactiveTextColor;
    tft.setFont(&FreeSans9pt7b);



    if (menuItemId == activeMenuItem) {
        bgColor=menuGroups[activeMenuGroup].activeColor;
        fgColor=menuGroups[activeMenuGroup].activeTextColor;
        tft.setFont(&FreeSansBold9pt7b);

    }
    

    tft.fillRoundRect(x, y, wip, hip, hip/2, bgColor);
    yield();
    tft.setCursor(x+10,y+(hip*.1)+14);
    tft.setTextColor(fgColor,bgColor);
    //tft.setTextSize(2);
    tft.println(menuGroups[activeMenuGroup].menuItems[menuItemId].label);
    yield();

    //tft.color565(0, i, 0)
}


void printCenterJustifiedText(const char* text, u_int16_t cy, bool isBold, uint16_t fgColor, uint16_t bgColor) {
  int16_t x1, y1;
  uint16_t w, h;

  tft.setTextColor(fgColor,bgColor);

  if (isBold == true)
    tft.setFont(&FreeSansBold9pt7b);
  else
    tft.setFont(&FreeSans9pt7b);
  
  tft.getTextBounds(text, 0, cy, &x1, &y1, &w, &h);
  int16_t startX = (screenWidth - w) / 2;


  tft.setCursor(startX,y1);
  tft.println(text);
}

void printPaginatedText(const char* text, uint16_t fgColor, uint16_t bgColor ) {

    //int pageNumber = 0;
    //int lastChar = 0;
    int16_t x1, y1;
    uint16_t w, h;
    //int maxCharsPerScreen = 0;
    int textLength = 0;
    byte linesPerScreen =13;
    //int avgCharWidth=0;
    byte charsPerLine = 38;
    bool stillReading = true;
    


    //for scrolling... 
    /*
      1. Determine text length (size HxW) for desired font.
      2. breakup the text into lines
      3. write only the lines that will fit based on scrol; cursor position

      change of plans
      WITH FreeSans9pt7b...
      16 characters per line 
      11 lines per screen.
    */

    tft.fillScreen(bgColor);
    tft.setTextColor(fgColor,bgColor);
    //                                xAdv   yAdv
    //tft.setFont(&FreeSans9pt7b); // 5-18     22   7
    tft.setFont(&FreeMono9pt7b); //   11     18   11
  // tft.setFont(&FreeSerif9pt7b); // 5-17     22    7
    textLength = strlen(text);
    //tft.getTextBounds("the quick, brown fox jumped over the lazy dog. THE QUICK, BROWN FOX JUMPED OVER THE LAZY DOG!", 0, 0, &x1, &y1, &w, &h);

    charsPerLine = screenWidth/11;
  //charsPerLine = 40;



    // maxCharsPerScreen = linesPerScreen * charsPerLine;

    //setup the text for proper formatting...
    int i=0,j=0,ch=0,lastSpaceInLine=0,lineCount=0,estTotalLines=((textLength/charsPerLine)*1.5)+3, chOffset = 0;
    //char lineBuffer[charsPerLine+1];
    char formattedText[estTotalLines][charsPerLine+1];

#ifdef DEBUG
    Serial.print(" linesPerScreen: ");
    Serial.print(linesPerScreen);
    // Serial.print(" test text width: ");
    // Serial.print(w);
    // Serial.print(" Average Char width (w/93): ");
    // Serial.print((w/93));
    Serial.print("; charsPerLine: ");
    Serial.print(charsPerLine);
    Serial.print("; textLength: ");
    Serial.print(textLength);
    Serial.print("; estTotalLines: ");
    Serial.println(estTotalLines);
#endif

    for (lineCount = 0; lineCount < estTotalLines && ch < textLength; lineCount++) {
        constantLights(0,1);

        for (i=0; i < charsPerLine && ch < textLength; i++) {
            constantLights(1,1);

            formattedText[lineCount][i] = text[ch];
            // if (text[ch] == ' ' || text[ch]  == '.' || text[ch]  == ',' || text[ch]  == ';' 
            //   || text[ch]  == ':' || text[ch]  == '!' || text[ch]  == '\n' || text[ch]  == '?')
            //   lastSpaceInLine = i;
            if (text[ch] == ' ' || text[ch]  == '\n' || text[ch]  == '-')
              lastSpaceInLine = i;
              ch++;
        } //for (i=0; i < charsPerLine && ch < (textLength-1); i++)
        constantLights(1,0);
        constantLights(2,1);

  /*
      scenarios                                                                     lastSpaceInLine                ch
        1. We've transversed the whole line (i = 38), we are still ch<textLength, 
          and there is a white space character before that but past 60% (23)       The last space encountered;    back to last white space.
        2. We've hit the end of the text (ch >= textLength)                         i-1;                           no change
        3. We've transversed the whole line (i = 38), we are still ch<textLength,   i-1;                           no change
          there is either no whitespace before 60%, but there is whitespace the 
          next character up.
        4. We've transversed the whole line (i = 38), we are still ch<textLength,   i-1;                           no change
          there is either no whitespace before 60%.
  */
        chOffset = 1;
        if ((ch < textLength  
        && (text[ch] == ' ' || text[ch]  == '\n' || text[ch]  == '-'))
        || ch >= textLength ) {
            lastSpaceInLine = i;  
        //  chOffset = -1;
#ifdef DEBUG
                Serial.print("White Space or end of text."); 
#endif
        }
#ifdef DEBUG
              Serial.print("; ch before offset: ");
              Serial.print(ch);
#endif

        if (lastSpaceInLine > 1 && ch < textLength) { 
          ch -= (charsPerLine - lastSpaceInLine)-chOffset;
        }
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

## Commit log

2025-11-17 resources added
    resources added
    [Arduino MCU profiles.ods, Internal components fit.FCStd, Punch List-Tricorder Build V1.ods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]
2025-11-22 Additional resources added. Prepping for switch to feather
2025-12-18 Added stls and 3d Printer objects. New readme updates. Support for 2.0" TFT and ESP-32 Feather
    [TRHV4-Button Surround.stl, TRHV4-Hood Front Panel Udrillit.stl, TRHV4-Hood Front Panel.3mf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]
2025-12-30 tweaked 3d models. added 2.0" screen. Made charting system. Works with lights off of MCU directly
    [Arduino MCU profiles.ods, Hood Wiring Harness.kicad_sch, Internal components fit.FCStd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]
